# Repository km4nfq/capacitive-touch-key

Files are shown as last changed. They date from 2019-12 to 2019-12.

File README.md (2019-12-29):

# Capacitive Touch Key

This key is based on the M0UKD Capacitive Touch Key described at:

https://m0ukd.com/homebrew/capacitive-cw-touch-key-circuits/

I modified the PCB to have through hole pads for the wiring.

This PCB can be ordered from OSH Park: 

https://oshpark.com/shared_projects/urEWNyZZ

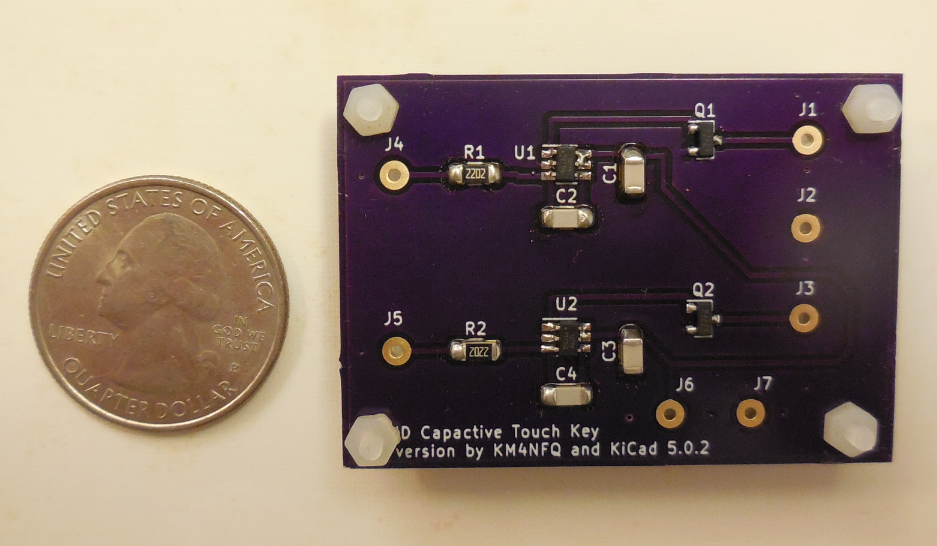
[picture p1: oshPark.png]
OSHPark


## Bill Of Materials

2 - 22K Ohm resistors, SMD 1206, Thick Film (R1, R2)

2 - 0.1uF capacitors, SMD 1206 (C1, C3)

2 - 2.2nF capacitors, SMD 1206 (C2, C4)

2 - IRFML8244 MOSFETs, SMD SOT-23 (Q1, Q2)

2 - AT42QT1011 Touch sensors, SMD (U1, U2)

1 - Capacitive Touch Paddle PCB (from your favorite Fab House)

1 - TRS Stereo Plug, 3.5mm, solder type

1 - AA battery holder

2 - AA Cells

2 - Conductive Paddle Material (Acorn Nuts, Angle Brackets, Etc.)

X - 22 AWG Stranded Hook-up Wire

1 - Enclosure

## Assembly

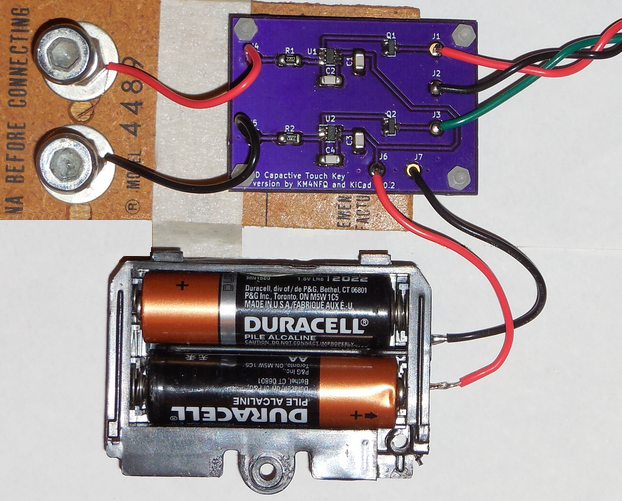
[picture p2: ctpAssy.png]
Capacitive Touch Paddle Assembly


### Power

J6 = +3V Battery (2 AA cells)

J7 = Battery GND

### Keyer

J1 = Tip

J2 = Sleeve

J3 = Ring

### Paddles

J4 = DIT

J5 = DAH

### Components

C1, C3 = 0.1uF Capacitors (1206)

C2, C4 = 2.2nF Capacitors (1206)

Q1, Q2 = IRFML8244 MOSFET (SOT-23)

R1, R2 = 22K Ohm Resistors (1206) Thick Film

U1, U2 = AT42QT1011 Touch Sensor (6-pin, Dot on Pin 1)

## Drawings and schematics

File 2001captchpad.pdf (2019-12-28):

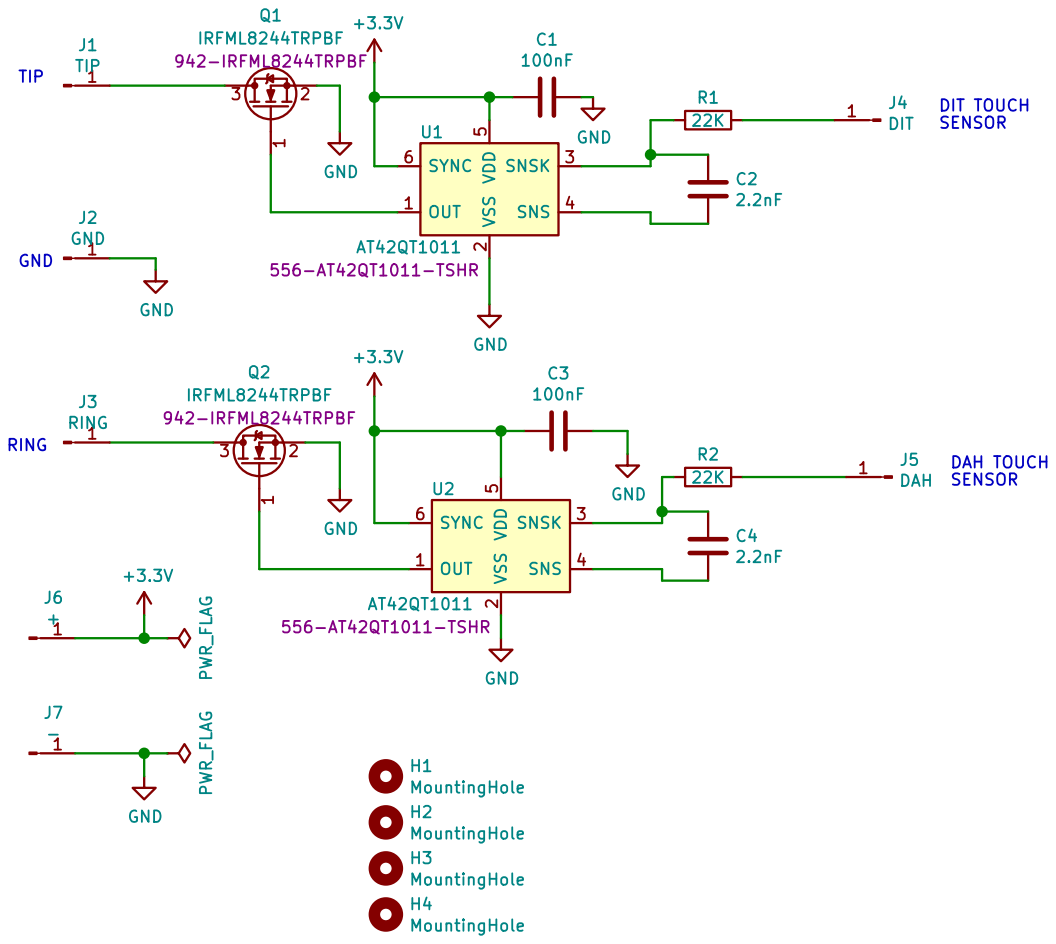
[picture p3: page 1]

22K OHM RESISTORS
2.2nF & 100nF CAPACITORS
File: 2001captchpad.sch Sheet: / KM4NFQ and KiCad 5.0.2

Id: 1/1 Title: M0UKD Capacitive Touch Key

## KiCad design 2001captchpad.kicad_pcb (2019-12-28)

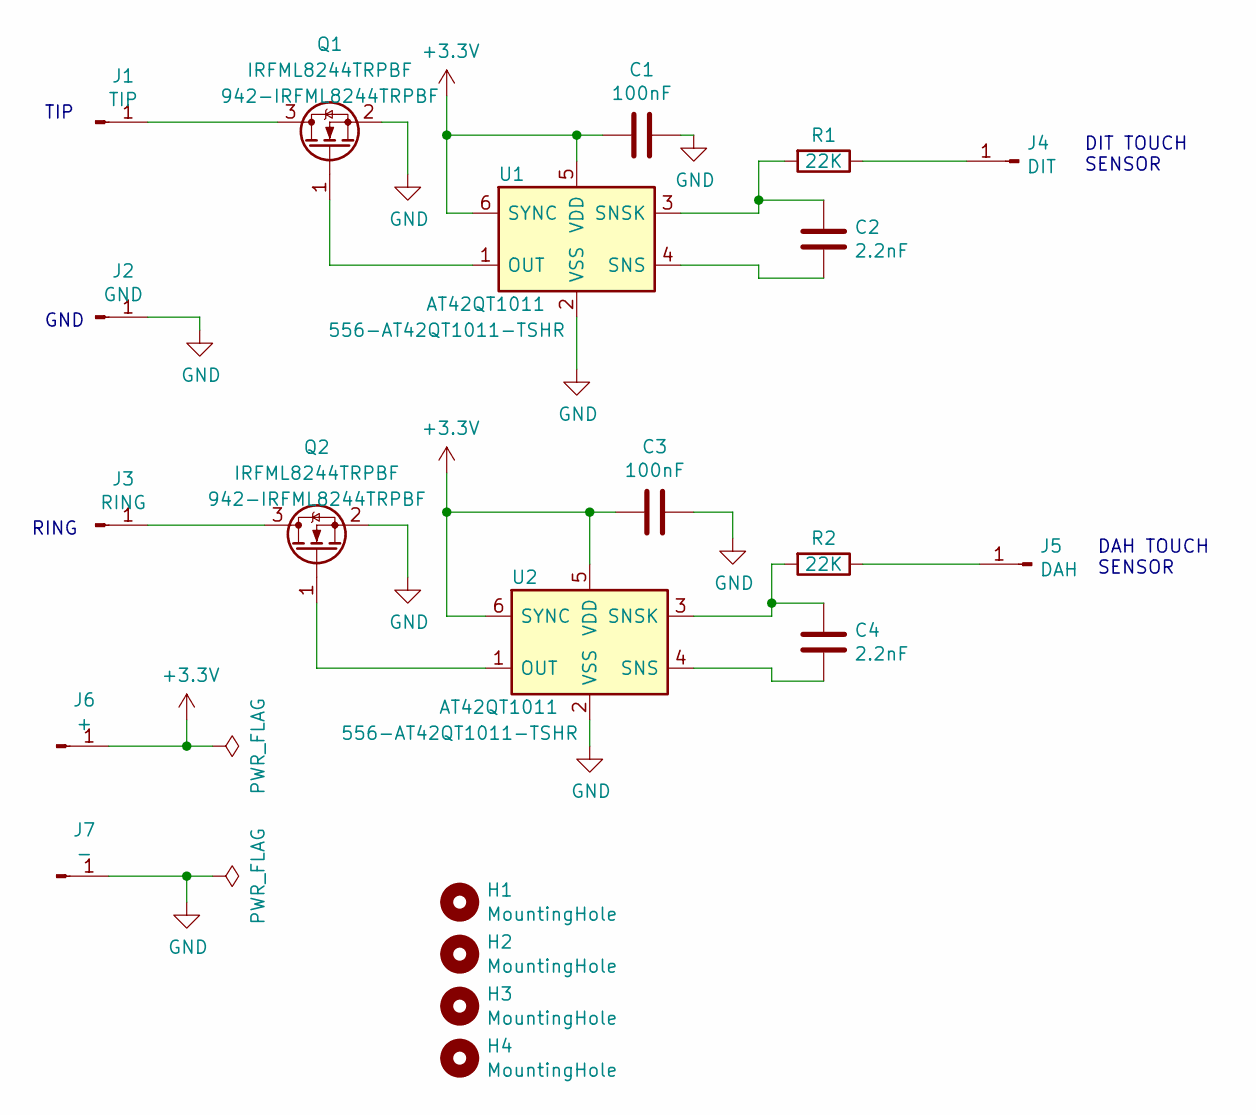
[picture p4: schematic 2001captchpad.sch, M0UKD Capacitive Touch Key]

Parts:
C1, C3: 100nF; C_1206_3216Metric_Pad1.42x1.75mm_HandSolder
C2, C4: 2.2nF; C_1206_3216Metric_Pad1.42x1.75mm_HandSolder
H1, H2, H3, H4: MountingHole; MountingHole_2.5mm
J1: TIP; SolderWirePad_1x01_Drill1mm
J2: GND; SolderWirePad_1x01_Drill1mm
J3: RING; SolderWirePad_1x01_Drill1mm
J4: DIT; SolderWirePad_1x01_Drill1mm
J5: DAH; SolderWirePad_1x01_Drill1mm
J6: +; SolderWirePad_1x01_Drill1mm
J7: -; SolderWirePad_1x01_Drill1mm
Q1, Q2: IRFML8244TRPBF; SOT-23
R1, R2: 22K; R_1206_3216Metric_Pad1.42x1.75mm_HandSolder
U1, U2: AT42QT1011; SOT-23-6_Handsoldering

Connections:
+3V3: C1.2, C3.2, J6.1, U1.5 (VDD), U1.6 (SYNC), U2.5 (VDD), U2.6 (SYNC)
GND: C1.1, C3.1, J2.1, J7.1, Q1.2 (S), Q2.2 (S), U1.2 (VSS), U2.2 (VSS)
unnamed: C2.1, R1.2, U1.3 (SNSK)
unnamed: C2.2, U1.4 (SNS)
unnamed: C4.1, R2.2, U2.3 (SNSK)
unnamed: C4.2, U2.4 (SNS)
unnamed: J1.1, Q1.3 (D)
unnamed: J3.1, Q2.3 (D)
unnamed: J4.1, R1.1
unnamed: J5.1, R2.1
unnamed: Q1.1 (G), U1.1 (OUT)
unnamed: Q2.1 (G), U2.1 (OUT)

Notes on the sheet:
DIT TOUCH SENSOR
DAH TOUCH SENSOR
TIP
RING
GND

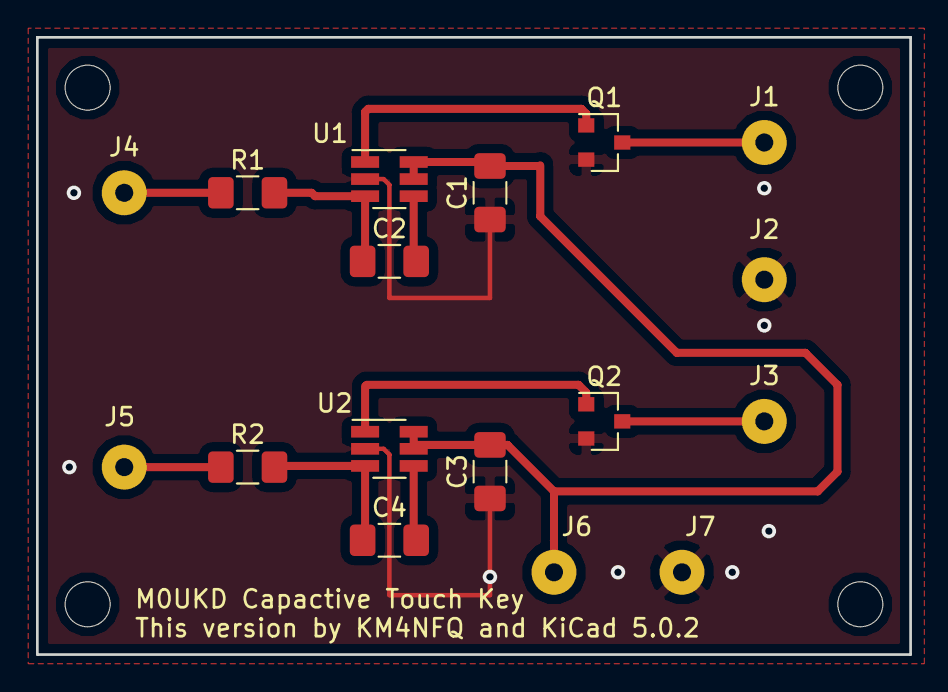
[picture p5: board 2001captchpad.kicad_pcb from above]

Board: 2 copper layers, 48.5 x 34.3 mm, 21 parts (0 on the bottom side), 12 nets.

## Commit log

2019-12-29 Deleted *.Silks.gbr files
    [2001captchpad-B.Silks.gbr, 2001captchpad-F.Silks.gbr]
2019-12-29 Gerbers re-plotted
    [2001captchpad-B.Cu.gbr, 2001captchpad-B.Mask.gbr, 2001captchpad-B.Paste.gbr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]
2019-12-30 Updated 20191229
    [2001captchpad.sch]
2020-01-03 Mirrored schematic
    [2001captchpad.sch]
